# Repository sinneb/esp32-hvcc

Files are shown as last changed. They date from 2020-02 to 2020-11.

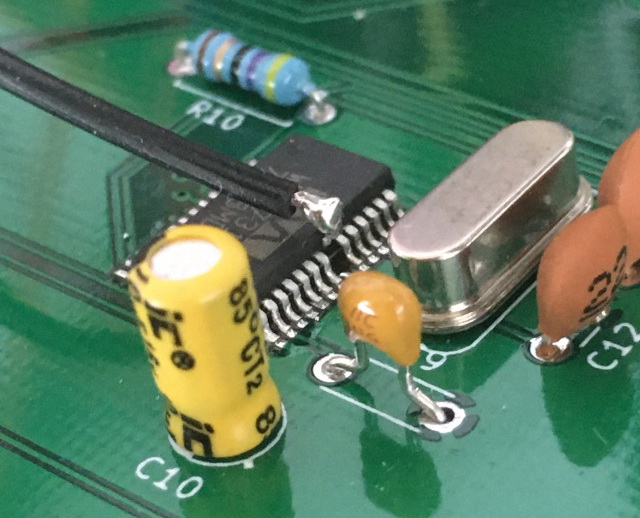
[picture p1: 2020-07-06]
proto2.jpg

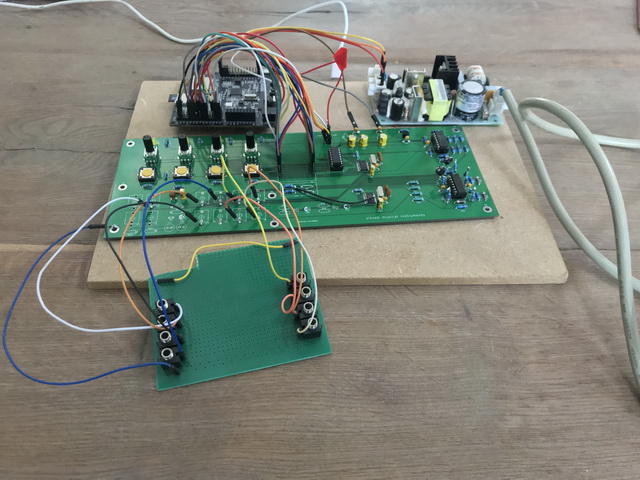
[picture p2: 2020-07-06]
proto1.jpg

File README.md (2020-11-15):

# ESP32-DevKitC & hvcc

This repo demonstrates a single file solution for running [hvcc](https://github.com/enzienaudio/hvcc) sources on the [ESP32-devkitc](https://docs.espressif.com/projects/esp-idf/en/latest/hw-reference/get-started-devkitc.html), inspired by the [Faust ESP32 architecture example](https://faust.grame.fr/doc/tutorials/#dsp-on-the-esp32-with-faust). The hvcc compiler leverages the use of (a subset of) puredata operators on the cheap and fast esp32 uprocessor. The ESP32-devkitc combined with one PCM5102 CODEC, one WM8731 CODEC and an 8 port MCP3208 ADC provides a complete and available audio development platform with a very reasonable pricetag. UI provided via 4 buttons, 4 potentiometers and 4 leds.

# Goal

The goal of this development is to realise a generic eurorack module that is based on the ESP32 and programmable via puredata. Each cheap module consists of four control voltage inputs and four audio / cv outputs (all io -5v -> +5v and fully eurorack compatible). All parts are easily obtainable and all software and hardware is open source, so ordering your own set of PCB's is also possible

# Status
15-nov-2020: Replaced one of the PCM5102 with a WM8731 to have audio stereo line in over i2s

25-oct-2020: PCB design ready, gerbers generated and boards ordered.

18-oct-2020: Code cleanup and PCB design ongoing. Current schematic tested and working!

# Installation

- Install Espressif IoT Development Framework 4.1, the official development framework for ESP32.
- Install the hvcc compiler
- Clone this repo

# Hardware setup

Check the Kicad schematics in the schematics folder

# Usage

- Create your puredata patch, using the [supported objects](supportedobjects.md) only. Use `tabread` with a $0-array instead of the `table` object, seems to work better.
- Issue a Issue a `python2.7 hvcc.py input.pd -o ./heavy/` to generate the source files, where input.pd is your puredata patch
- MAC: compile using hvcc and libs and copy to project subdir: `python2.7 hvcc.py esp32_2.pd -p ./Hoclib/ ./Josephlarralde/ ./ParkinsonHashizume/ ./MikeMorenoAudio/ ./Heavylib -o ./heavy/ ; cp ./heavy/c/Heavy_heavy.* ~/Documents/GitHub/esp32-hvcc/main/heavy/`
- WIN: compile and copy: `c:\Python27\python.exe` rest as above, then a `copy /Y heavy\c\Heavy_* c:\Users\Arthur\Github\esp32-hvcc\main\heavy`
- Add all heavy c and cpp sources to /main/CMakeLists.txt (only when adding new objects)
- Run `idf.py -p /dev/tty.SLAB_USBtoUART flash monitor` to compile, upload and monitor the esp32 binary
- MAC: `idf.py -p /dev/cu.usbserial-1A14301 -b 921600 flash monitor`
- WIN: `idf.py -p COM4 -b 921600 flash monitor`
- Enjoy your pd patch!

# Performance

A large and nice sounding puredata patch from "manwithfeathers" on rebeltech.org named ["Fascination IV"](https://www.rebeltech.org/patch-library/patch/Fascination_IV) yields about 60% performance of the ESP32 which looks like a very nice performance / cost ratio!

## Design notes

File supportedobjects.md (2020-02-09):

Supported puredata objects:

-   `<`
-   `<<`
-   `<=`
-   `==`
-   `>`
-   `>=`
-   `>>`
-   `|`
-   `||`
-   `-`
-   `-~`
-   `!=`
-   `/`
-   `/~`
-   `*`
-   `*~`
-   `&`
-   `&&`
-   `%`
-   `+`
-   `+~`
-   `abs`
-   `abs~`
-   `adc~`
-   `atan`
-   `atan2`
-   `b`
-   `bang`
-   `bendin`
-   `bendout`
-   `biquad~`
-   `bng`
-   `bp~`
-   `catch~`
-   `change`
-   `clip`
-   `clip~`
-   `cnv`
-   `cos`
-   `cos~`
-   `cpole~`
-   `ctlin`
-   `ctlout`
-   `czero~`
-   `czero_rev~`
-   `dac~`
-   `dbtopow`
-   `dbtopow~`
-   `dbtorms`
-   `dbtorms~`
-   `declare`
-   `del`
-   `delay`
-   `delread~`
-   `delwrite~`
-   `div`
-   `env~`
-   `exp`
-   `exp~`
-   `f`
-   `float`
-   `floatatom`
-   `ftom`
-   `ftom~`
-   `hip~`
-   `hradio`
-   `hsl`
-   `i`
-   `inlet`
-   `inlet~`
-   `int`
-   `line`
-   `line~`
-   `loadbang`
-   `log`
-   `lop~`
-   `makenote`
-   `max`
-   `max~`
-   `metro`
-   `min`
-   `min~`
-   `mod`
-   `moses`
-   `mtof`
-   `mtof~`
-   `nbx`
-   `noise~`
-   `notein`
-   `noteout`
-   `osc~`
-   `outlet`
-   `outlet~`
-   `pack`
-   `pgmin`
-   `pgmout`
-   `phasor~`
-   `pipe`
-   `poly`
-   `pow`
-   `pow~`
-   `powtodb`
-   `powtodb~`
-   `print`
-   `q8_rsqrt~`
-   `q8_sqrt~`
-   `r`
-   `r~`
-   `random`
-   `receive`
-   `receive~`
-   `rmstodb`
-   `rmstodb~`
-   `route`
-   `rpole~`
-   `rsqrt~`
-   `rzero~`
-   `rzero_rev~`
-   `s`
-   `s~`
-   `samphold~`
-   `samplerate~`
-   `sel`
-   `select`
-   `send`
-   `send~`
-   `sig~`
-   `sin`
-   `snapshot~`
-   `spigot`
-   `sqrt`
-   `sqrt~`
-   `swap`
-   `symbol`
-   `symbolatom`
-   `t`
-   `table`
-   `tabosc4~`
-   `tabplay~`
-   `tabread`
-   `tabread~`
-   `tabread4~`
-   `tabwrite`
-   `tabwrite~`
-   `tan`
-   `tgl`
-   `throw~`
-   `timer`
-   `touchin`
-   `touchout`
-   `trigger`
-   `unpack`
-   `until`
-   `vcf~`
-   `vd~`
-   `vradio`
-   `vsl`
-   `wrap`
-   `wrap~`

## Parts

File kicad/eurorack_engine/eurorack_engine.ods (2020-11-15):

Id | Designator | Package | Quantity | Designation | Supplier and ref
1 | H6,H5,H4,H3,H1,H2 | MountingHole_3.2mm_M3 | 6 | MountingHole
2 | LM4040 | TO-92_Inline | 1 | LM4040LP-10
3 | LM1117 | TO-220-3_Vertical | 1 | LM1117-3.3 | Tayda | A-628
4 | MCP6004 | DIP-14_W7.62mm_Socket | 1 | MCP6004
5 | TL074 | DIP-14_W7.62mm_Socket | 1 | TL074
6 | MCP3208 | DIP-16_W7.62mm | 1 | MCP3208
7 | RV4,RV3,RV2,RV1 | Potentiometer_Alps_RK09K_Single_Vertical | 4 | R_POT | Tayda | A-1870
8 | R34 | R_Axial_DIN0207_L6.3mm_D2.5mm_P7.62mm_Horizontal | 1 | 2k2
9 | R33 | R_Axial_DIN0207_L6.3mm_D2.5mm_P7.62mm_Horizontal | 1 | 4r7
10 | R32,R31,R20,R19,R18,R17,R6,R5 | R_Axial_DIN0207_L6.3mm_D2.5mm_P7.62mm_Horizontal | 8 | 1k
11 | R30,R29,R16,R15 | R_Axial_DIN0207_L6.3mm_D2.5mm_P7.62mm_Horizontal | 4 | 33k
12 | R28,R27,R24,R23,R12,R11,R8,R7,R38,R37,R36,R35 | R_Axial_DIN0207_L6.3mm_D2.5mm_P7.62mm_Horizontal | 12 | 10k
13 | R26,R25,R14,R13 | R_Axial_DIN0207_L6.3mm_D2.5mm_P7.62mm_Horizontal | 4 | 100k
14 | R22,R21,R10,R9 | R_Axial_DIN0207_L6.3mm_D2.5mm_P7.62mm_Horizontal | 4 | 200k
15 | PWR_SEL1 | PinHeader_1x02_P2.54mm_Vertical | 1 | Conn_01x02
16 | J9 | PinHeader_2x05_P2.54mm_Vertical | 1 | EURO_PWR_2x5
17 | out 4 | PJ301M-12 | 1 | codec out 4 | Tayda | A-2563
18 | out 2 | PJ301M-12 | 1 | codec out 2
19 | in 3 | PJ301M-12 | 1 | cv in 3
20 | in 4 | PJ301M-12 | 1 | cv in 4
21 | out 3 | PJ301M-12 | 1 | codec out 3
22 | out 1 | PJ301M-12 | 1 | codec out 1
23 | in 1 | PJ301M-12 | 1 | cv in 1
24 | in 2 | PJ301M-12 | 1 | cv in 2
25 | C7,C6,C5,C4,C3 | C_Disc_D4.3mm_W1.9mm_P5.00mm | 5 | 100n
26 | C2,C1 | C_Radial_D6.3mm_H5.0mm_P2.50mm | 2 | 47uf
27 | SW4,SW3,SW2,SW1 | SW_PUSH-12mm | 4 | SW_Push
28 | R4,R3,R2,R1 | R_Axial_DIN0207_L6.3mm_D2.5mm_P7.62mm_Horizontal | 4 | 220r
29 | PCM5102,PCM5102 | PCM5102 | 2 | PCM5102
30 | D4,D3,D2,D1 | LED_D5.0mm | 4 | LED
31 | U1 | MODULE_ESP32-DEVKITC-32D | 1 | ESP32-DEVKITC-32D

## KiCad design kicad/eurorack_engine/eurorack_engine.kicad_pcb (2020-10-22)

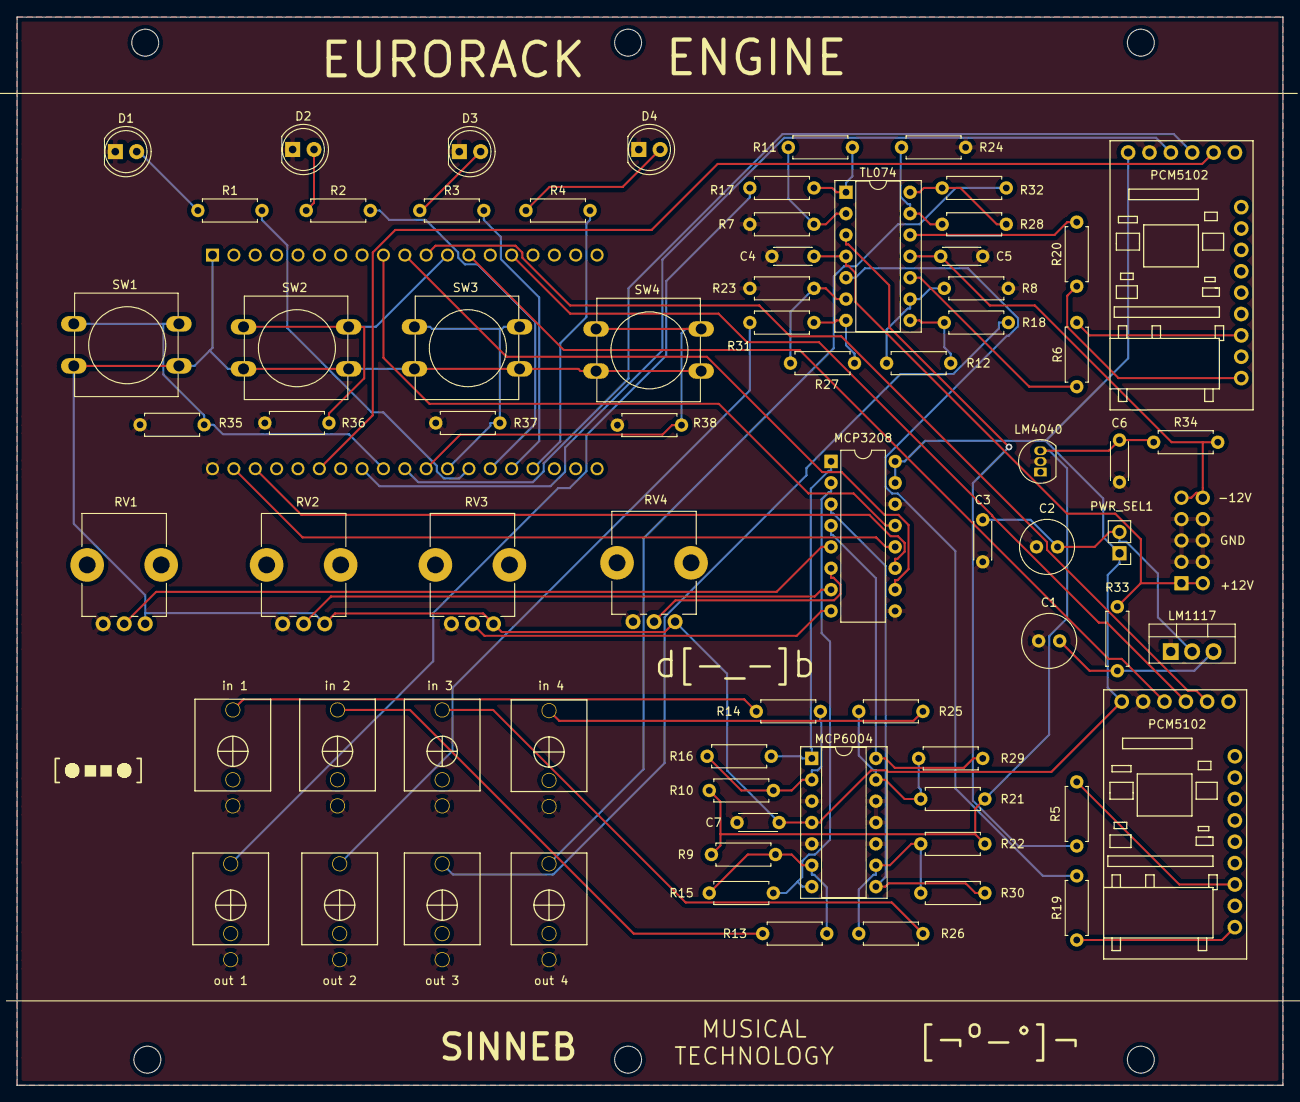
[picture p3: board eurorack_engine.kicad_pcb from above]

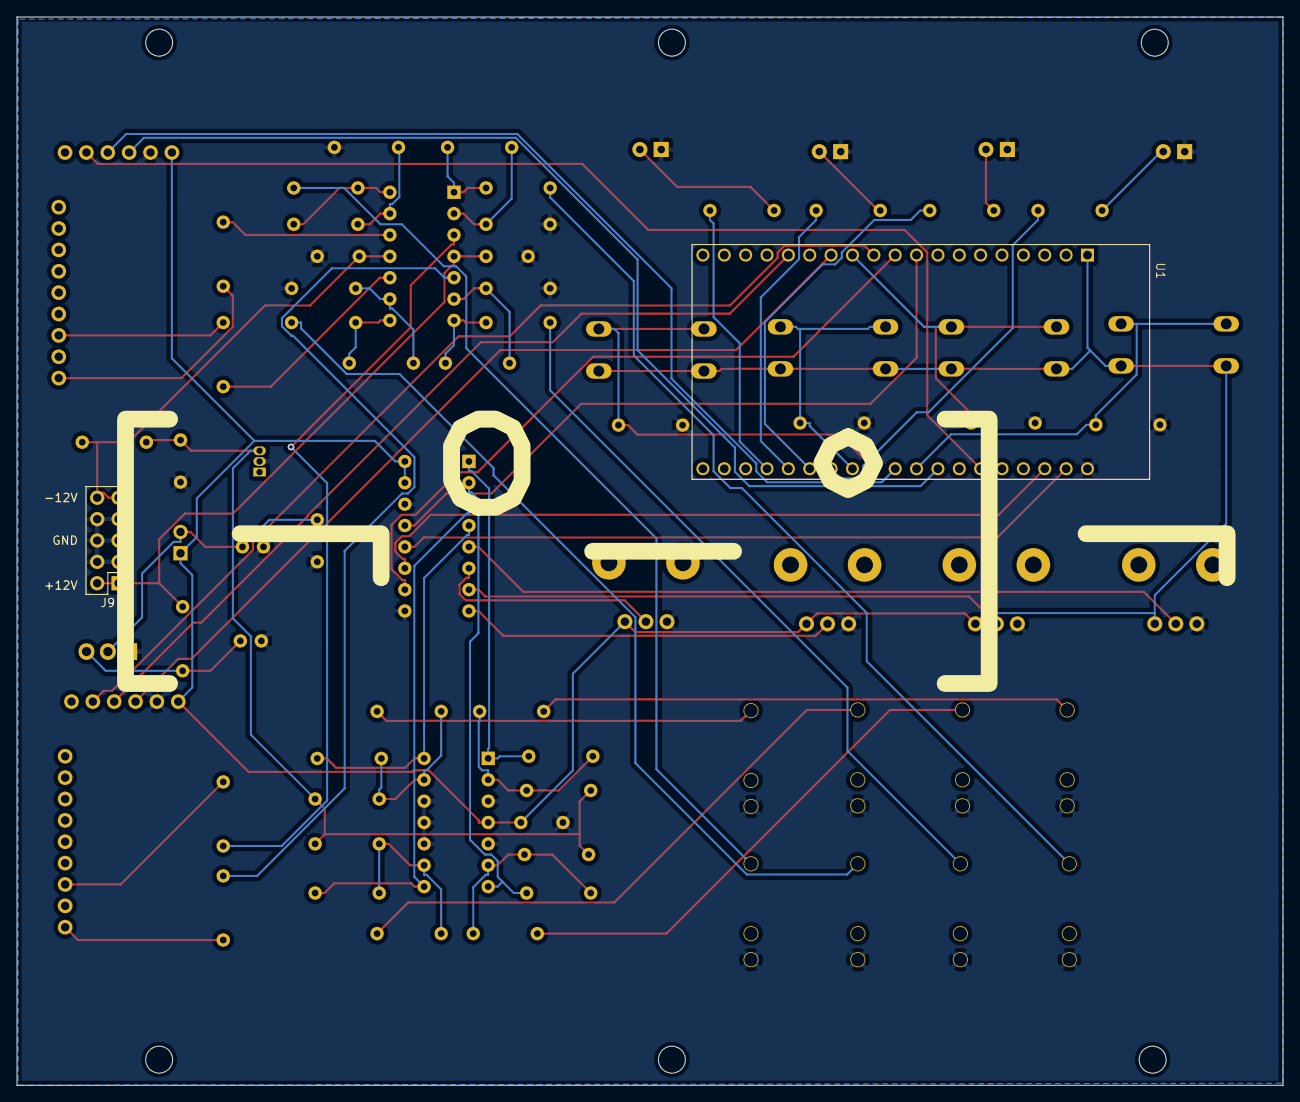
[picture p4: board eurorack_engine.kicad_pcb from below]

Board: 2 copper layers, 150.5 x 127.0 mm, 81 parts (2 on the bottom side), 65 nets.

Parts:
C1, C2: 47uf; C_Radial_D6.3mm_H5.0mm_P2.50mm
C3, C4, C5, C6, C7: 100n; C_Disc_D4.3mm_W1.9mm_P5.00mm
D1, D2, D3, D4: LED; LED_D5.0mm
H1, H2, H3, H4, H5, H6: MountingHole; MountingHole_3.2mm_M3
J9: EURO_PWR_2x5; PinHeader_2x05_P2.54mm_Vertical
LM1117: LM1117-3.3; TO-220-3_Vertical
LM4040: LM4040LP-10; TO-92_Inline
MCP3208: MCP3208; DIP-16_W7.62mm
MCP6004: MCP6004; DIP-14_W7.62mm_Socket
PCM5102, PCM5102#2: PCM5102
PWR_SEL1: Conn_01x02; PinHeader_1x02_P2.54mm_Vertical
R1, R2, R3, R4: 220r; R_Axial_DIN0207_L6.3mm_D2.5mm_P7.62mm_Horizontal
R5, R6, R17, R18, R19, R20, R31, R32: 1k; R_Axial_DIN0207_L6.3mm_D2.5mm_P7.62mm_Horizontal
R7, R8, R11, R12, R23, R24, R27, R28, R35, R36, R37, R38: 10k; R_Axial_DIN0207_L6.3mm_D2.5mm_P7.62mm_Horizontal
R9, R10, R21, R22: 200k; R_Axial_DIN0207_L6.3mm_D2.5mm_P7.62mm_Horizontal
R13, R14, R25, R26: 100k; R_Axial_DIN0207_L6.3mm_D2.5mm_P7.62mm_Horizontal
R15, R16, R29, R30: 33k; R_Axial_DIN0207_L6.3mm_D2.5mm_P7.62mm_Horizontal
R33: 4r7; R_Axial_DIN0207_L6.3mm_D2.5mm_P7.62mm_Horizontal
R34: 2k2; R_Axial_DIN0207_L6.3mm_D2.5mm_P7.62mm_Horizontal
RV1, RV2, RV3, RV4: R_POT; Potentiometer_Alps_RK09K_Single_Vertical
SW1, SW2, SW3, SW4: SW_Push; SW_PUSH-12mm
TL074: TL074; DIP-14_W7.62mm_Socket
U1: ESP32-DEVKITC-32D; MODULE_ESP32-DEVKITC-32D
in 1: cv in 1; PJ301M-12
in 2: cv in 2; PJ301M-12
in 3: cv in 3; PJ301M-12
in 4: cv in 4; PJ301M-12
out 1: codec out 1; PJ301M-12
out 2: codec out 2; PJ301M-12
out 3: codec out 3; PJ301M-12
out 4: codec out 4; PJ301M-12

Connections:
+3V3: C7.2, MCP3208.15, MCP3208.16, MCP6004.4, PCM5102.1, PCM5102#2.1, PWR_SEL1.1, RV1.1, RV2.1, RV3.1, RV4.1, SW1.2, SW2.2, SW3.2, SW4.2, U1.1
+12V: C4.2, J9.1, J9.2, R33.1, TL074.4
-12V: C5.1, J9.9, J9.10, R34.2, TL074.11
/adc_ch0: MCP3208.1, MCP6004.1, R16.2
/adc_ch1: MCP3208.2, MCP6004.7, R15.2
/adc_ch2: MCP3208.3, MCP6004.8, R30.2
/adc_ch3: MCP3208.4, MCP6004.14, R29.2
/adc_ch4: MCP3208.5, RV1.2
/adc_ch5: MCP3208.6, RV4.2
/adc_ch6: MCP3208.7, RV2.2
/adc_ch7: MCP3208.8, RV3.2
/adc_clk: MCP3208.13, U1.9
/adc_cs: MCP3208.10, U1.10
/adc_miso: MCP3208.12, U1.21
/adc_mosi: MCP3208.11, U1.22
/aref_-10v: C6.1, LM4040.3, R9.1, R10.1, R21.1, R22.1, R34.1
/bck1: PCM5102#2.5, U1.11
/bck2: PCM5102.5, U1.25
/button1: R36.2, SW2.1, U1.12
/button2: R37.2, SW3.1, U1.31
/button3: R38.2, SW4.1, U1.30
/button4: R35.2, SW1.1, U1.28
/codec_out_1: PCM5102#2.13, R5.1
/codec_out_2: PCM5102#2.15, R19.1
/codec_out_3: PCM5102.13, R6.1
/codec_out_4: PCM5102.15, R20.1
/din1: PCM5102#2.4, U1.15
/din2: PCM5102.4, U1.29
/led1: R1.2, U1.32
/led2: R2.2, U1.33
/led3: R3.2, U1.34
/led4: R4.2, U1.35
/lrck1: PCM5102#2.3, U1.13
/lrck2: PCM5102.3, U1.27
GND: C1.2, C2.2, C3.1, C4.1, C5.2, C6.2, C7.1, D1.1, D2.1, D3.1, D4.1, J9.3, J9.4, J9.5, J9.6, J9.7, J9.8, LM1117.1, LM4040.2, MCP3208.9, MCP3208.14, MCP6004.3, MCP6004.5, MCP6004.10, MCP6004.11, MCP6004.12, PCM5102.2, PCM5102#2.2, R7.2, R8.2, R23.2, R24.2, R35.1, R36.1, R37.1, R38.1, RV1.3, RV2.3, RV3.3, RV4.3, U1.20, in 1.1, in 2.1, in 3.1, in 4.1, out 1.1, out 2.1, out 3.1, out 4.1
unnamed: C1.1, LM1117.3, R33.2
unnamed: C2.1, C3.2, LM1117.2, PWR_SEL1.2
unnamed: D1.2, R1.1
unnamed: D2.2, R2.1
unnamed: D3.2, R3.1
unnamed: D4.2, R4.1
unnamed: R13.1, in 2.3
unnamed: R14.1, in 1.3
unnamed: R17.2, out 1.3
unnamed: R18.2, out 3.3
unnamed: R25.1, in 4.3
unnamed: R26.1, in 3.3
unnamed: R31.2, out 2.3
unnamed: R32.2, out 4.3
unnamed: R5.2, TL074.3
unnamed: R6.2, TL074.10
unnamed: MCP6004.2, R10.2, R14.2, R16.1
unnamed: R7.1, R11.1, TL074.2
unnamed: R11.2, R17.1, TL074.1
unnamed: R8.1, R12.1, TL074.9
unnamed: R12.2, R18.1, TL074.8
unnamed: MCP6004.6, R9.2, R13.2, R15.1
unnamed: R19.2, TL074.5
unnamed: R20.2, TL074.12
unnamed: MCP6004.13, R21.2, R25.2, R29.1
unnamed: MCP6004.9, R22.2, R26.2, R30.1
unnamed: R23.1, R27.1, TL074.6
unnamed: R24.1, R28.1, TL074.13
unnamed: R27.2, R31.1, TL074.7
unnamed: R28.2, R32.1, TL074.14

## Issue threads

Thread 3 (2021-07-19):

Connecting and configuring wm8731 proto board

smutax, 2021-07-19:
Hi there. Loving this project. Hope it is still being maintained. Can you advise please how one needs to modify the schematic in order to connect and utilize wm8731 based breakout board(mikroe-506)?
https://www.mikroe.com/audio-codec-proto-board
All the best and stay safe.

sinneb, 2022-02-07:
Hi Smutax. Thank you for your interest and sorry for this very late reply. I've started working on this project again. For now I'm planning a simplification of the project with only PCM5102's to get underway. The WM8731 will be a future upgrade.

smutax, 2022-02-07:
Hi @sinneb! Glad you are going back to this project. Just a heads up, please see https://github.com/ctag-fh-kiel/ctag-tbd/issues/53 where @dromer mentions your  project. Hope some collaboration or contribution will come out of that. Many thanks and keep up the good work.

sinneb, 2022-02-08:
Thanks for the pointer towards TBD, I'm looking into it now!

Closed 2022-02-07.

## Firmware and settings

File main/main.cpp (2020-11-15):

#include <stdio.h>
#include "freertos/FreeRTOS.h"
#include "freertos/task.h"
#include "freertos/queue.h"
#include "esp_system.h"
#include "esp_spi_flash.h"
#include "esp_log.h"
#include <sys/time.h>
#include "WM8978.h"
#include "driver/i2s.h"
#include "Heavy_heavy.h"
#include "esp32/rom/ets_sys.h"
#include "esp32/rom/gpio.h"
#include "esp_intr_alloc.h"
#include "esp_attr.h"
#include "driver/timer.h"
#include "driver/gpio.h"
#include "driver/ledc.h"

// // OLED display drivers & settings
#include <driver/spi_master.h>

#include "ad1939defs.cpp"
// #include "u8g2_esp32_hal.h"
// u8g2_t u8g2; // a structure which will contain all the data for one display

// #include "rotary_encoder.h"
// #define ROT_ENC_A_GPIO 14
// #define ROT_ENC_B_GPIO 27
// #define ENABLE_HALF_STEPS false  // Set to true to enable tracking of rotary encoder at half step resolution
// #define RESET_AT          0      // Set to a positive non-zero number to reset the position if this value is exceeded
// #define FLIP_DIRECTION    true  // Set to true to reverse the clockwise/counterclockwise sense

#define LEDC_IO_0    (5)

#define ESP_INTR_FLAG_DEFAULT 0

#define LEDC_HS_TIMER          LEDC_TIMER_0
#define LEDC_HS_MODE           LEDC_HIGH_SPEED_MODE
#define LEDC_HS_CH0_GPIO       (12)
#define LEDC_HS_CH0_CHANNEL    LEDC_CHANNEL_0

int fadelevel = 0;

#define MULT_S32 1826500000
#define MULT_S24 8388607
//#define MULT_S32 2147483647
//#define MULT_S32 1373741823
#define ADC_CS 15 // chip 10

static xQueueHandle gpio_evt_queue = NULL;
static xQueueHandle i2sDMA = NULL;

static const char* TAG = "EurorackEngine";

float *inBuffers;
float *outBuffers;
HeavyContextInterface *context;
int blockSize = 16;
uint8_t i2s_ready=1;
uint8_t calc_busy = 0;

int32_t calib[32];

uint16_t dmareqs = 0;

size_t free8start, free32start, free8, free32;

static intr_handle_t s_timer_handle;
static intr_handle_t s_timer_handle2;

static int io_state = 0;

uint32_t teller = 0;
uint32_t teller2 = 0;

//RX TX Buffers
uint8_t tx_data[10];
uint8_t rx_data[10];

//uint16_t dmabuf[2500];
uint8_t displaybuffer1refresh = 1;
uint16_t displaybuffer1[128];
uint16_t displaybuffer1zoom = 8;
uint16_t displaybuffer1counter = 0;
uint16_t displaybuffer1subcounter = 0;
uint32_t displaybuffer1temp = 0;

uint16_t adcvalues[8][10];
uint8_t adccounter = 0;
uint8_t adcmax = 4;
uint8_t potentiometercounter=0;

// global spi handle
spi_device_handle_t spi;

// global spi_transaction_t
spi_transaction_ext_t t;
spi_transaction_ext_t *t_res;

static const char* tag = "heavy";

extern "C" {
    void app_main(void);
}

static void timeval_subtract(struct timeval *result, struct timeval *end, struct timeval *start) {
  if (end->tv_usec < start->tv_usec) {
    result->tv_sec = end->tv_sec - start->tv_sec - 1;
    result->tv_usec = 1000000L + end->tv_usec - start->tv_usec;
  } else {
    result->tv_sec = end->tv_sec - start->tv_sec;
    result->tv_usec = end->tv_usec - start->tv_usec;
  }
}

static void timer_tg0_isr(void* arg)
{
  teller++;
	//Reset irq and set for next time
  TIMERG0.int_clr_timers.t0 = 1;
  TIMERG0.hw_timer[0].config.alarm_en = 1;
  // get spi transaction result, dont wait
  spi_device_get_trans_result(spi, (spi_transaction_t**)&t_res, 0);
  // store result in adc array
  // adc[0] -> adc[3] : incoming CV values, no running average
  // adc[4] -> adc[7] : potentiometers, running averages (?)
  adcvalues[adccounter][0] = (rx_data[1] << 4) | (rx_data[2] >> 4);

  // set ADC port
  adccounter++;
  // reset ADC count
  // scan adc0 - adc3 (CV inputs) 10x more often,
  if(adccounter==adcmax) {
    adccounter = 0;
    potentiometercounter++;
    if(potentiometercounter==8) {
      adcmax=8;
    }
    if(potentiometercounter==9) {
      adcmax=4;
      potentiometercounter = 0;
    }
  }
  uint8_t pin = adccounter;
  tx_data[0] = 0b01100000 | ((pin & 0b111) << 2);

  if(adccounter==4) teller2++;

  // place next transaction in queue, dont wait
  spi_device_queue_trans(spi, (spi_transaction_t*)&t, 0);

    // ---- CALCULATE OSCILLOSCOPE
    // // display calculations are done here to distribute the calculation-load more evenly
    // if(displaybuffer1refresh==1) {
    //   if(displaybuffer1subcounter < displaybuffer1zoom) {
    //     displaybuffer1temp+=(rx_data[1] << 4) | (rx_data[2] >> 4);
    //     displaybuffer1subcounter++;
    //   } else {
    //     displaybuffer1[displaybuffer1counter]=displaybuffer1temp/displaybuffer1zoom;
    //     displaybuffer1temp=0;
    //     displaybuffer1subcounter=0;
    //     displaybuffer1counter++;
    //     if(displaybuffer1counter==128){displaybuffer1counter=0;displaybuffer1refresh=0;}
    //   }
    // }
    // /-- CALCULATE
}

void timer_tg0_initialise (int timer_period_us)
{
  timer_config_t config = {
          .alarm_en = (timer_alarm_t)true,				  //Alarm Enable
          .counter_en = (timer_start_t)false,			  //If the counter is enabled it will start incrementing / decrementing immediately after calling timer_init()
          .intr_type = TIMER_INTR_LEVEL,	          //Is interrupt is triggered on timer’s alarm (timer_intr_mode_t)
          .counter_dir = TIMER_COUNT_UP,	          //Does counter increment or decrement (timer_count_dir_t)
          .auto_reload = (timer_autoreload_t)true,	//If counter should auto_reload a specific initial value on the timer’s alarm, or continue incrementing or decrementing.
          .divider = 80   				                  //Divisor of the incoming 80 MHz (12.5nS) APB_CLK clock. E.g. 80 = 1uS per timer tick
  };

  timer_init(TIMER_GROUP_0, TIMER_0, &config);
  timer_set_counter_value(TIMER_GROUP_0, TIMER_0, 0);
  timer_set_alarm_value(TIMER_GROUP_0, TIMER_0, timer_period_us);
  timer_enable_intr(TIMER_GROUP_0, TIMER_0);
  timer_isr_register(TIMER_GROUP_0, TIMER_0, &timer_tg0_isr, NULL, 0, &s_timer_handle);

  timer_start(TIMER_GROUP_0, TIMER_0);
}

uint8_t recvbuf=6;

uint32_t spiget(spi_device_handle_t spi, uint8_t reg)
{
  //
  unsigned char result = 0;
  unsigned char data[3];

  data[0] = ((0x04<<1)|1);
  data[1] = reg;      // reg
  data[2] = 0x0;
  //char sendbuf[16]="Hello World!"
  spi_transaction_t t;
  memset(&t, 0, sizeof(t));
  t.length=8*3;
  t.tx_buffer=&data;
  t.rx_buffer=&recvbuf;
  t.flags = SPI_TRANS_USE_RXDATA;
  t.user = (void*)1;

  esp_err_t ret=spi_device_polling_transmit(spi, &t);
  assert(ret==ESP_OK);

  return *(uint32_t*)t.rx_data;
}

void spi_write_reg(spi_device_handle_t spi, uint8_t reg, uint8_t val)
{
  //
  unsigned char result = 0;
  unsigned char data[3];

  data[0] = ((0x04<<1));
  data[1] = reg;      // reg
  data[2] = val;
  //char sendbuf[16]="Hello World!"
  spi_transaction_t t;
  memset(&t, 0, sizeof(t));
  t.length=8*3;
  t.tx_buffer=&data;
  //t.rx_buffer=&recvbuf;
  //t.flags = SPI_TRANS_USE_RXDATA;
  t.user = (void*)0;

  esp_err_t ret=spi_device_polling_transmit(spi, &t);
  assert(ret==ESP_OK);

  //return *(uint32_t*)t.rx_data;
}

void printram() {
  ESP_LOGI(TAG, "RAM left %d", esp_get_free_heap_size());

  free8start = heap_caps_get_free_size(MALLOC_CAP_8BIT);
free32start = heap_caps_get_free_size(MALLOC_CAP_32BIT);
printf("Free 8bit-capable memory (start): %dK, 32-bit capable memory %dK\n", free8start, free32start);
}

void displayHandler(void *pvParameter)
{
  uint8_t xpos = 10;

  while(true) {

    printf("teller: %d\n", teller);
    printf("teller2: %d\n", teller2);
    printf("ADC0: %d\n", adcvalues[0][0]);
    printf("ADC1: %d\n", adcvalues[1][0]);
    printf("ADC2: %d\n", adcvalues[2][0]);
    printf("ADC3: %d\n", adcvalues[3][0]);
    printf("ADC4: %d\n", adcvalues[4][0]);
    printf("ADC5: %d\n", adcvalues[5][0]);
    printf("ADC6: %d\n", adcvalues[6][0]);
    printf("ADC7: %d\n", adcvalues[7][0]);
    printf("\n");
    printram();

    // app main
    // I (1262) EurorackEngine: RAM left 299960
//     I (3502) EurorackEngine: RAM left 264300
// ADC7: 1094
//
// I (3502) EurorackEngine: RAM left 264300
// I (3512) EurorackEngine: heap 261888
// I (3512) EurorackEngine: heap 229444
// heavys # outputs: 4
// heavsy # inputs: 2
// [@ 0.000ms] print: seconds
// teller: 41283
// teller2: 1032
// ADC0: 11
// ADC1: 16
// ADC2: 15
// ADC3: 9
// ADC4: 1420
// ADC5: 720
// ADC6: 2557
// ADC7: 1095
//
// I (4512) EurorackEngine: RAM left 41928

    //
    // // ledc_set_duty(LEDC_LOW_SPEED_MODE, LEDC_CHANNEL_0, fadelevel);
    // // ledc_update_duty(LEDC_LOW_SPEED_MODE, LEDC_CHANNEL_0);
    // // //
    // // ledc_set_duty(LEDC_LOW_SPEED_MODE, LEDC_CHANNEL_1, fadelevel);
    // // ledc_update_duty(LEDC_LOW_SPEED_MODE, LEDC_CHANNEL_1);
    //
    // // ledc_set_duty(LEDC_LOW_SPEED_MODE, LEDC_CHANNEL_2, fadelevel);
    // // ledc_update_duty(LEDC_LOW_SPEED_MODE, LEDC_CHANNEL_2);
    //
    // fadelevel+=100;
    // if(fadelevel>1000)fadelevel=0;
    //printf("-->");
    //uint32_t lcd_id = spiget(spi, 1);
    //printf("--> lock? \n");
    //ESP_LOGI(TAG, "RAM left %d", esp_get_free_heap_size());
    //lcd_id = spiget(spi, 3);
    //printf("--> 0: %08X\n", lcd_id);
    //printf("dma: %d\n",dmareqs);
    //dmareqs = 0;


    //printf("lock?: %d\n",recvbuf);

    vTaskDelay(10000 / portTICK_RATE_MS);
  }
}

static void IRAM_ATTR gpio_isr_handler(void* arg)
{
    //uint32_t gpio_num = (uint32_t) arg;
    //xQueueSendFromISR(gpio_evt_queue, &gpio_num, NULL);
}


int ledstate = 0;
static void gpioHandler(void* arg)
{
  // uint32_t i2s_evt;
  // for(;;) {
  //   xQueueReceive(i2sDMA, &i2s_evt, portMAX_DELAY);
  //   //if (i2s_evt.type == I2S_EVENT_TX_DONE) {
  //   //printf("yo\n");
  //   dmareqs++;
  //   if(dmareqs==8) {
  //     if(ledstate==0) {
  //       gpio_set_level((gpio_num_t)13, 1);
  //       ledstate = 1;
  //     } else {
  //       gpio_set_level((gpio_num_t)13, 0);
  //       ledstate = 0;
  //     }
  //     dmareqs=0;
  //
  //   }
  //   //}
  // }
    uint32_t io_num;
    for(;;) {
        if(xQueueReceive(gpio_evt_queue, &io_num, portMAX_DELAY)) {
            printf("GPIO[%d] intr, val: %d\n", io_num, gpio_get_level((gpio_num_t)io_num));
            //hv_sendFloatToReceiver(context, HV_HEAVY_PARAM_IN_BUT1, (float)gpio_get_level((gpio_num_t)io_num));
        }
    }
}

void printHook(HeavyContextInterface *c, const char *printName, const char *str, const HvMessage *m) {
  double timestampMs = 1000.0 * ((double) hv_msg_getTimestamp(m)) / hv_getSampleRate(c);
  printf("[@ %.3fms] %s: %s\n", timestampMs, printName, str);
}

// define the send hook as a function with the following signature
static void sendHook(HeavyContextInterface *c,
    const char *sendName, unsigned int sendHash, const HvMessage *m) {

  // // only react to messages sent to receivers named "hello"
  // if (!strcmp(sendName, "hello")) {
  //   // do something with the message
  //   printf("> received message from send \"%s\".", sendName);
  // }

  // printf(sendName);
  // printf("\n");

  if (!strcmp(sendName, "led1")) {
      uint16_t x = hv_msg_getFloat(m, 0);
      ledc_set_duty(LEDC_LOW_SPEED_MODE, LEDC_CHANNEL_0, x);
      ledc_update_duty(LEDC_LOW_SPEED_MODE, LEDC_CHANNEL_0);
    }

  if (!strcmp(sendName, "led2")) {
      uint16_t x = hv_msg_getFloat(m, 0);
      //printf("led 2 val %d",x);
      ledc_set_duty(LEDC_LOW_SPEED_MODE, LEDC_CHANNEL_1, x);
      ledc_update_duty(LEDC_LOW_SPEED_MODE, LEDC_CHANNEL_1);
    }

    if (!strcmp(sendName, "led3")) {
        uint16_t x = hv_msg_getFloat(m, 0);
        ledc_set_duty(LEDC_LOW_SPEED_MODE, LEDC_CHANNEL_2, x);
        ledc_update_duty(LEDC_LOW_SPEED_MODE, LEDC_CHANNEL_2);
      }

    if (!strcmp(sendName, "led4")) {
        uint16_t x = hv_msg_getFloat(m, 0);
        ledc_set_duty(LEDC_LOW_SPEED_MODE, LEDC_CHANNEL_3, x);
        ledc_update_duty(LEDC_LOW_SPEED_MODE, LEDC_CHANNEL_3);
      }

  // // or alternatively...
  // printf("hash: %d\n", sendHash);
  //printf("hier");
  // printf("\n");
  // switch (sendHash) {
  //   case HV_HEAVY_PARAM_OUT_LED1: {
  //     printf("led1\n");
  //     uint16_t x = hv_msg_getFloat(m, 0);
  //     ledc_set_duty(LEDC_LOW_SPEED_MODE, LEDC_CHANNEL_0, x);
  //     ledc_update_duty(LEDC_LOW_SPEED_MODE, LEDC_CHANNEL_0);
  //   }
  //   case HV_HEAVY_PARAM_OUT_LED2: {
  //     //printf("led2\n");
  //     uint16_t y = hv_msg_getNumElements(m);
  //     uint16_t x = hv_msg_getFloat(m, 0);
  //     printf("val %d\n",x);
  //     printf("numele: %d\n",y);
  //     ledc_set_duty(LEDC_LOW_SPEED_MODE, LEDC_CHANNEL_1, x);
  //     ledc_update_duty(LEDC_LOW_SPEED_MODE, LEDC_CHANNEL_1);
  //   }
    // case HV_HEAVY_PARAM_OUT_LED3: {
    //   printf("led3\n");
    //   uint16_t x = hv_msg_getFloat(m, 0);
    //   ledc_set_duty(LEDC_LOW_SPEED_MODE, LEDC_CHANNEL_2, x);
    //   ledc_update_duty(LEDC_LOW_SPEED_MODE, LEDC_CHANNEL_2);
    // }
    // case 0xFB81D83A: {
    //   // do something with the message
    //   printf("> message for you sir \"%s\".\n", sendName);
    //   uint16_t x = hv_msg_getFloat(m, 0);
    //   //printf("floatval: %d \n",x);
    //   ledc_set_duty(LEDC_LOW_SPEED_MODE, LEDC_CHANNEL_2, x);
    //   ledc_update_duty(LEDC_LOW_SPEED_MODE, LEDC_CHANNEL_2);
    //   break;
    // }
    //default: return;
  //}
}
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
void app_main()
{
    printf("app main\n");

    printram();

    // setup global spi_transaction_t
    t_res = &t;
    memset(&t, 0, sizeof(t));
    t.base.length = 24;
    t.base.tx_buffer = &tx_data;
    t.base.rxlength = 24;
    t.base.rx_buffer = &rx_data;
    tx_data[0] = 24;
    tx_data[1] = 0;

    esp_err_t ret;

    spi_bus_config_t buscfg={
        .mosi_io_num=22,      // chip 11
        .miso_io_num=23,      // chip 12 *19
        .sclk_io_num=25,      // chip 13 *18
        .quadwp_io_num=-1,
        .quadhd_io_num=-1
    };
    spi_device_interface_config_t devcfg={
        .mode=0,
        .clock_speed_hz=2000000,
        .spics_io_num=26,     // 10
        .queue_size=1,
    };





//     uint32_t lcd_id = spiget(spi, 3);
//     printf("LCD3  ID: %08X\n", lcd_id);
//     printf("LCD 3 ID: %d\n", lcd_id);
//     printf("res: %d\n",recvbuf);
//
//     vTaskDelay(1000 / portTICK_RATE_MS);
//
//      lcd_id = spiget(spi,12);
//     printf("LCD 12 ID: %08X\n", lcd_id);
//     printf("res: %d\n",recvbuf);
//
//     vTaskDelay(1000 / portTICK_RATE_MS);
//
//      lcd_id = spiget(spi,1);
//     printf("LCD 1 ID: %08X\n", lcd_id);
//     printf("LCD 1 ID: %d\n", lcd_id);
//     printf("res: %d\n",recvbuf);
//
// vTaskDelay(1000 / portTICK_RATE_MS);
//
//      lcd_id = spiget(spi,8);
//     printf("LCD8 ID: %08X\n", lcd_id);
//     printf("LCD8 ID: %d\n", lcd_id);
//     printf("res: %d\n",recvbuf);

//Initialize the SPI bus
ret=spi_bus_initialize(HSPI_HOST, &buscfg, 2);
ESP_ERROR_CHECK(ret);
//Attach the LCD to the SPI bus
ret=spi_bus_add_device(HSPI_HOST, &devcfg, &spi);
ESP_ERROR_CHECK(ret);

gpio_reset_pin((gpio_num_t)27);
gpio_set_direction((gpio_num_t)27, GPIO_MODE_OUTPUT);
gpio_set_level((gpio_num_t)27,0);

    WM8978 wm8978;
    wm8978.init(0);
    printf("starting wm8731.2\n");
printram();
    //rtc_clk_apll_enable(1, 0, 0, 4, 0);
    //WM8978 wm8978_2;
    //wm8978_2.init(1);

    // printf("starting display\n");
    // init_SSD1306();

    // start I2S
    i2s_pin_config_t pin_config;
    i2s_pin_config_t pin_config2;
    pin_config = {                  // 0 -> 25 MCLK
        .bck_io_num = 27,           // 3 SCK
        .ws_io_num = 12,            // 5 7 LRCLK
        .data_out_num = 13,         // 4 DACDAT
        .data_in_num = 34           // 6 ADCDAT
    };
    pin_config2 = {                  // 0 -> 25 MCLK
        .bck_io_num = 21,           // 3 SCK
        .ws_io_num = 19,            // 5 7 LRCLK
        .data_out_num = 5,         // 4 DACDAT
        //.data_in_num = 34          // 6 ADCDAT
    };
    i2s_config_t i2s_config = {
        .mode = (i2s_mode_t)(I2S_MODE_MASTER | I2S_MODE_TX | I2S_MODE_RX),
        .sample_rate = 48000,
        .bits_per_sample = (i2s_bits_per_sample_t)24,
        //.channel_num = 4,
        .channel_format = I2S_CHANNEL_FMT_RIGHT_LEFT,
        .communication_format = (i2s_comm_format_t)(I2S_COMM_FORMAT_I2S |I2S_COMM_FORMAT_I2S_MSB),
        .intr_alloc_flags = ESP_INTR_FLAG_LEVEL2, // high interrupt priority, level 2 because of HSPI conflict @ level 1
        .dma_buf_count = 6,
        .dma_buf_len = 60,
        //.use_apll = true,
        //.tx_desc_auto_clear   = false,
        //.fixed_mclk           = 0
        //.fixed_mclk = 40000000
    };
    // i2s_config_t i2s_config = {
    //     .mode = (i2s_mode_t)(I2S_MODE_MASTER | I2S_MODE_TX),
    //     .sample_rate = 48000,
    //     .bits_per_sample = (i2s_bits_per_sample_t)32,
    //     //.channel_num = 4,
    //     .channel_format = I2S_CHANNEL_FMT_RIGHT_LEFT,
    //     .communication_format = (i2s_comm_format_t)(I2S_COMM_FORMAT_I2S |I2S_COMM_FORMAT_I2S_MSB),
    //     .intr_alloc_flags = ESP_INTR_FLAG_LEVEL2, // high interrupt priority, level 2 because of HSPI conflict @ level 1
    //     .dma_buf_count = 6,
    //     .dma_buf_len = 60,
    //     .use_apll = true,
    //     //.tx_desc_auto_clear   = false,
    //     //.fixed_mclk           = 0
    //     //.fixed_mclk = 40000000
    // };
    //
    // i2s_config_t i2s_wm8731 = {
    //     .mode = (i2s_mode_t)(I2S_MODE_MASTER | I2S_MODE_TX),
    //     .sample_rate = 48000,
    //     .bits_per_sample = (i2s_bits_per_sample_t)32,
    //     .channel_format = I2S_CHANNEL_FMT_RIGHT_LEFT,
    //     .communication_format = (i2s_comm_format_t)(I2S_COMM_FORMAT_I2S |I2S_COMM_FORMAT_I2S_MSB),
    //     .intr_alloc_flags = ESP_INTR_FLAG_LEVEL2, // high interrupt priority
    //     .dma_buf_count = 6,
    //     .dma_buf_len = 60,
    //     .use_apll = true,
    //     //.use_apll = true,
    //     //.fixed_mclk = 12288000
    // };

    // I2S0.conf_chan.tx_chan_mod = 0x1;
    // I2S0.fifo_conf.tx_fifo_mod = 0x1;
    // I2S0.sample_rate_conf.tx_bck_div_num = 2;
    // I2S0.int_ena.out_eof = 1;
    // I2S0.out_link.start = 1;
    // I2S0.conf.tx_start = 1;

    //i2sDMA = xQueueCreate(10, sizeof(uint32_t));

    esp_err_t err;
    printf("i2s port 0 \n");
    err = i2s_driver_install((i2s_port_t)0, &i2s_config, 0, NULL);
    if (err != ESP_OK) {
      printf("Failed installing driver: %d\n", err);
      while (true);
    }
    err = i2s_set_pin((i2s_port_t)0, &pin_config);
    if (err != ESP_OK) {
      printf("Failed setting pin: %d\n", err);
      while (true);
    }

    printf("i2s port 1 \n");
    err = i2s_driver_install((i2s_port_t)1, &i2s_config, 0, NULL);
    if (err != ESP_OK) {
    printf("Failed installing driver: %d\n", err);
      while (true);
    }
    err = i2s_set_pin((i2s_port_t)1, &pin_config2);
    if (err != ESP_OK) {
      printf("Failed setting pin: %d\n", err);
      while (true);
    }
printram();
    // i2s_driver_install((i2s_port_t)1, &i2s_wm8731, 0, NULL);


    //vTaskDelay(3000 / portTICK_RATE_MS);





    PIN_FUNC_SELECT(PERIPHS_IO_MUX_GPIO0_U, FUNC_GPIO0_CLK_OUT1);
    WRITE_PERI_REG(PIN_CTRL, READ_PERI_REG(PIN_CTRL) & 0xFFFFFFF0);

    // gpio_set_direction((gpio_num_t)0, GPIO_MODE_OUTPUT);
    // PIN_FUNC_SELECT(PERIPHS_IO_MUX_GPIO0_U, FUNC_GPIO0_CLK_OUT1);
    // REG_WRITE(PIN_CTRL,0);

    //vTaskDelay(3000 / portTICK_RATE_MS);


    // VSPI DMA Channel 2
    // ret=spi_bus_initialize(VSPI_HOST, &buscfg, 2);
    // assert(ret==ESP_OK);
    // ret=spi_bus_add_device(VSPI_HOST, &devcfg, &spi);
    // assert(ret==ESP_OK);
    //queue a single transaction to set things up
    spi_device_queue_trans(spi, (spi_transaction_t*)&t, 100);

    // Start ADC callback
    printf("start ADC callback \n");
    timer_tg0_initialise(50);
    printf("ADC callback started \n");
printram();
    // let the ADC flow
    vTaskDelay(1000 / portTICK_RATE_MS);
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

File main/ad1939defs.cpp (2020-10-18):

/*The global address for the AD1938 is 0x04, shifted left one bit due to the R/W bit.*/
#define AD1938_GLOBAL_ADDRESS   0x04

#define AD1938_WRITE_ADDRESS    (AD1938_GLOBAL_ADDRESS<<1)
#define AD1938_READ_ADDRESS     ((AD1938_GLOBAL_ADDRESS<<1)|1)

#define AD1938_SPI_WRITE_BYTE_COUNT   3
#define AD1938_SPI_READ_BYTE_COUNT    2

/*------------------------------------------------------------------------------*/
/*PLL and Clock Control 0                                                       */
/*------------------------------------------------------------------------------*/
#define AD1938_PLL_CLK_CTRL0    0x00

/*
Bit Value Function Description
0 0 Normal operation PLL power-down
1 Power-down
2:1 00 INPUT 256 (× 44.1 kHz or 48 kHz) MCLKI/XI pin functionality (PLL active), master clock rate setting
    01 INPUT 384 (× 44.1 kHz or 48 kHz)
    10 INPUT 512 (× 44.1 kHz or 48 kHz)
    11 INPUT 768 (× 44.1 kHz or 48 kHz)
4:3 00 XTAL oscillator enabled MCLKO/XO pin, master clock rate setting
    01 256 × fS VCO output
    10 512 × fS VCO output
    11 Off
6:5 00 MCLKI/XI PLL input
    01 DLRCLK
    10 ALRCLK
    11 Reserved
7 0 Disable: ADC and DAC idle Internal master clock enable
  1 Enable: ADC and DAC active
*/

#define DIS_ADC_DAC         (0x00)
#define ENA_ADC_DAC         (0x80)

#define PLL_IN_MCLK         (0x00)
#define PLL_IN_DLRCLK       (0x20)
#define PLL_IN_ALRCLK       (0x40)

#define MCLK_OUT_XTAL       (0x00)
#define MCLK_OUT_256FS      (0x08)
#define MCLK_OUT_512FS      (0x10)
#define MCLK_OUT_OFF        (0x18)

#define INPUT256            (0x00)
#define INPUT384            (0x02)
#define INPUT512            (0x04)
#define INPUT768            (0x06)

#define PLL_PWR_UP          (0x00)
#define PLL_PWR_DWN         (0x01)

/*------------------------------------------------------------------------------*/
/*PLL and Clock Control 1                                                       */
/*------------------------------------------------------------------------------*/
#define AD1938_PLL_CLK_CTRL1     0x01
/*
Bit Value Function Description
0 0 PLL clock DAC clock source select
1 MCLK
1 0 PLL clock ADC clock source select
1 MCLK
2 0 Enabled On-chip voltage reference
1 Disabled
3 0 Not locked PLL lock indicator (read-only)
  1 Locked
7:4 0000 Reserved
*/
#define AD1938_PLL_LOCK     (0x08)

#define DIS_VREF            (0x04)
#define ENA_VREF            (0x00)

#define ADC_CLK_PLL         (0x00)
#define ADC_CLK_MCLK        (0x20)

#define DAC_CLK_PLL         (0x00)
#define DAC_CLK_MCLK        (0x01)

/*------------------------------------------------------------------------------*/
/*        DAC Control 0                                                         */
/*------------------------------------------------------------------------------*/
#define AD1938_DAC_CTRL0         0x02
/*
Bit Value Function Description
0 0 Normal Power-down
1 Power-down
2:1 00 32 kHz/44.1 kHz/48 kHz Sample rate
    01 64 kHz/88.2 kHz/96 kHz
    10 128 kHz/176.4 kHz/192 kHz
    11 Reserved
5:3 000 1 SDATA delay (BCLK periods)
    001 0
    010 8
    011 12
    100 16
    101 Reserved
    110 Reserved
    111 Reserved
7:6 00 Stereo (normal) Serial format
    01 TDM (daisy chain)
    10 DAC AUX mode (ADC-, DAC-, TDM-coupled)
    11 Dual-line TDM
*/
#define DAC_FMT_I2S         (0x00)
#define DAC_FMT_TDM         (0x40)
#define DAC_FMT_AUX         (0x80)
#define DAC_FMT_DUALTDM     (0xc0)


#define DAC_BCLK_DLY_1      (0x00)
#define DAC_BCLK_DLY_0      (0x08)
#define DAC_BCLK_DLY_8      (0x01)
#define DAC_BCLK_DLY_12     (0x18)
#define DAC_BCLK_DLY_16     (0x20)

#define DAC_SR_48K          (0x00)
#define DAC_SR_96K          (0x02)
#define DAC_SR_192K         (0x04)

#define DAC_PWR_UP          (0x00)
#define DAC_PWR_DWN         (0x01)
/*------------------------------------------------------------------------------*/
/*        DAC Control 1                                                         */
/*------------------------------------------------------------------------------*/
#define AD1938_DAC_CTRL1        0x03

/*
Bit Value Function Description
0   0 Latch in mid cycle (normal) BCLK active edge (TDM in)
1 Latch in at end of cycle (pipeline)
2:1 00 64 (2 channels) BCLKs per frame
    01 128 (4 channels)
    10 256 (8 channels)
    11 512 (16 channels)
3 0 Left low LRCLK polarity
  1 Left high
4 0 Slave LRCLK master/slave
  1 Master
5 0 Slave BCLK master/slave
  1 Master
6 0 DBCLK pin BCLK source
  1 Internally generated
7 0 Normal BCLK polarity
  1 Inverted
*/

#define DAC_BCLK_POL_NORM       (0x00)
#define DAC_BCLK_POL_INV        (0x80)

#define DAC_BCLK_SRC_PIN        (0x00)
#define DAC_BCLK_SRC_INTERNAL   (0x40)

#define DAC_BCLK_SLAVE          (0x00)
#define DAC_BCLK_MASTER         (0x20)

#define DAC_LRCLK_SLAVE         (0x00)
#define DAC_LRCLK_MASTER        (0x10)

#define DAC_LRCLK_POL_NORM      (0x00)
#define DAC_LRCLK_POL_INV       (0x08)
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

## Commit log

2020-02-11 Added u8g2 drivers for SSD1306 OLED display
2020-02-17 added rotary encoder support
2020-02-19 Added 12khz ADC read over VSPI & DMA
2020-02-29 added schematics, fixed oled
    [eurogen.kicad_pcb, eurogen.sch]
2020-03-01 added rotary encoder. schematics PDF
    [eurogen.sch]
2020-03-06 pin numbers updates, continued work on ADC
    [eurogen.sch]
2020-03-06 succesful dma buffer experiments
2020-03-08 changes to make WM8731 master
    countering:
    problems with reliable i2c
    problems with dual codec
    [WM8978.cpp, WM8978.h, main.cpp]
2020-03-08 WM8731 i2c fixed
    changed resistor values
    confirmed schematic
    [eurogen.sch]
2020-03-14 i2c with auto retry, fixes for double i2s
    [WM8978.cpp, WM8978.h, main.cpp]
2020-03-20 gpio updates, schematics update
    [eurogen.sch]
2020-03-22 schematic updates
    [eurogen.sch]
2020-03-27 before cleanup
    [eurogen.sch]
2020-04-12 fixed button in
    now both 26 and 32 work
    [main.cpp]
2020-04-13 pwm led 0, 2 and 5 working
    [eurogen.sch]
2020-04-17 sendhook implemented
    [eurogen.sch]
2020-04-30 led fixes and small cleanup
    [eurogen.sch]
2020-05-08 fixes and updates
    adc sample rate
    pd patch communication
    [main.cpp]
2020-05-10 wm8731 fixes
    [eurogen.sch]
2020-05-14 schematics update
    [eurogen.sch]
2020-10-18 push before rework
    [adc.sch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]
2020-10-18 code cleanup
    [eurogen-B_Cu.gbr, eurogen-B_Mask.gbr, eurogen-B_SilkS.gbr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]
2020-10-19 schematic update
    [eurorack_engine.kicad_pcb, inout.sch, power.sch]
2020-10-21 updated schematics
    [adc.sch, eurorack_engine.kicad_pcb, eurorack_engine.sch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]
2020-10-22 schematic final
    [eurorack_engine-B_Cu.gbr, eurorack_engine-B_Mask.gbr, eurorack_engine-B_SilkS.gbr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]
